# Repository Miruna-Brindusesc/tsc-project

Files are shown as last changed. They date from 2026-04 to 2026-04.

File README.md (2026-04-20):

# Proiect InkTime: Smartwatch nRF52840

## 1\. Diagrama Bloc

Diagrama de mai jos ilustreaza interconexiunile dintre unitatea centrala (MCU) si perifericele sistemului.

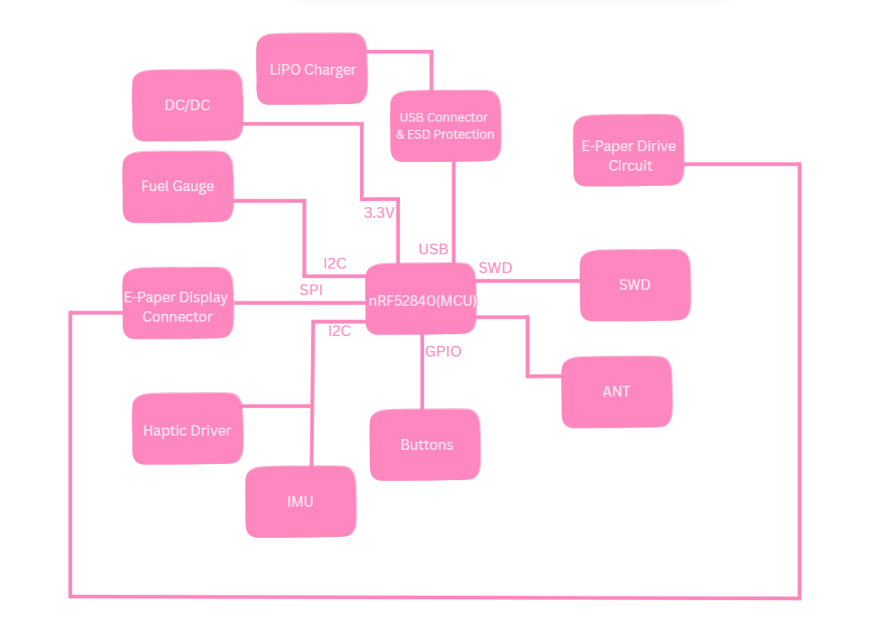
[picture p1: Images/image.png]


## 2\. Descriere Hardware

Ceasul este construit in jurul lui **nRF52840**, ales special pentru ca e foarte eficient si are Bluetooth inclus. Ideea de baza: consumam curent doar cand e absolut necesar.

### 2.1. Creierul (MCU)
* **nRF52840:** Un cip puternic care stie si Bluetooth 5.0 si USB. Are doua cristale de cuart pentru precizie maxima la masurarea timpului.
* **Antena:** Semnalul pleaca spre o antena ceramica. Ca sa avem semnal bun, am decupat planul de cupru de sub ea (zona de "keep-out").

### 2.2. Power & Battery
* **incarcare (BQ25180):** Se ocupa de alimentarea bateriei LiPo prin USB-C. il controlam prin **I2C** ca sa stim cand s-a incarcat.
* **Fuel Gauge (MAX17048):** E senzorul. Ne spune exact cat % mai are bateria, cu o eroare de sub 1%.
* **Regulator (RT6160A):** Transforma tensiunea variabila a bateriei intr-un **3.3V stabil** pentru toate componentele.
* **Protectie ESD:** Langa mufa USB-C am pus un cip minuscul (USBLC6) care atenueaza socurile de electricitate statica sa nu prajim placa.

### 2.3. Ecran si Vibratii
* **E-Paper Display:** Cel mai mare avantaj. Consuma curent **doar cand schimba imaginea**. Daca ceasul sta pe loc, consumul e zero.
* **Driverul de ecran:** Pentru ca ecranul are nevoie de tensiuni mari ca sa miste cerneala electronica, am adaugat un circuit special cu diode si condensatori de 50V.
* **Vibratii (Haptic):** Folosim un driver **DRV2605** care misca motorasul. E mult mai destept decat un simplu tranzistor, oferind vibratii mai fine.

### 2.4. Senzori si Butoane
* **Miscare (BMA423):** Accelerometrul care numara pasii. L-am legat pe **I2C** si are pini de intrerupere (INT) ca sa „trezeasca” ceasul cand ridici mana.
* **Butoane:** Avem 3 butoane cu filtre hardware (rezistente si condensatori) ca sa nu avem probleme cu „apasarile false” (debounce).

## 3\. Asociere pini

| Grupa de pini | Pini folositi | Componenta | Justificarea alegerii / Functia |
| :--- | :--- | :--- | :--- |
| **I2C (SDA/SCL)** | **P0.26 / P0.27** | BQ25180, MAX17048, BMA423, DRV2605 | Magistrala comuna; pinii au fost pozitionati departe de zona antenei pentru a evita interferentele RF. |
| **Display (SPI)** | **P0.13, P0.14, P0.19** | E-Paper Connector | Rutare scurta si directa catre conectorul FPC, minimizand lungimea traseelor de mare viteza. |
| **Display Control** | **P0.20, P0.21, P0.23** | E-Paper Connector | Pini GPIO pentru semnalele de DC, Reset si Busy. Pinul Busy actioneaza ca intrerupere (INT). |
| **Power Gate** | **P0.24** | Tranzistor Q1 (Load Switch) | Ofera curent suficient pentru a comuta poarta MOSFET-ului, oprind complet ecranul in standby. |
| **Butoane & Alerte**| **P1.00 - P1.06** | Butoane externe, Alerte IMU / Baterie | Folosirea exclusiva a Portului 1 pentru semnale lente/intreruperi, izolandu-le de magistralele de date si permitand functia de Wake-Up eficient. |
| **Haptic Enable** | **P0.25** | DRV2605 (Motor Haptic) | Pin GPIO folosit pentru pornirea/oprirea cipului haptic. |
| **USB** | **VBUS, D+, D-** | Conector USB-C | Pini hardware dedicati ai PHY-ului intern nRF52840 pentru comunicatie nativa. |
| **Programare (SWD)** | **SWDIO, SWDCLK, SWO**| Conector Tag-Connect | Pini dedicati din fabrica pentru interfata Serial Wire Debug. |
| **Ceas (Oscilator)** | **P0.00, P0.01** | Cristal 32.768 kHz | Pini hardware dedicati (LFXO) pentru conectarea cristalului extern necesar functiilor de Low-Power Sleep. |

## 4\. BOM
| Qty | Componenta | Designator | Cod JLC / Sursa | Datasheet / Link |
| :--- | :--- | :--- | :--- | :--- |
| 1 | **nRF52840 (MCU)** | U1 | [C190740](https://www.google.com/search?q=https://jlcpcb.com/partdetail/NordicSemicon-NRF52840_QIAA/C190740) | [Datasheet](https://www.google.com/search?q=https://infocenter.nordicsemi.com/pdf/nRF52840_PS_v1.1.pdf) |
| 1 | **BMA423 (IMU)** | IC3 | [C262-BMA423](https://jlcpcb.com/parts) | [Datasheet](https://www.google.com/search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) |
| 1 | **BQ25180 (Charger)** | IC1 | [C595-BQ25180](https://jlcpcb.com/parts) | [Datasheet](https://www.ti.com/lit/ds/symlink/bq25180.pdf) |
| 1 | **MAX17048 (Fuel Gauge)** | U3 | [C329239](https://jlcpcb.com/parts) | [Datasheet](https://www.google.com/search?q=https://datasheets.maximintegrated.com/en/ds/MAX17048-MAX17049.pdf) |
| 1 | **RT6160A (DC/DC)** | IC9 | [C835-RT6160](https://jlcpcb.com/parts) | [Datasheet](https://www.google.com/search?q=https://www.richtek.com/assets/product_pdf/RT6160A/DS6160A-02.pdf) |
| 1 | **DRV2605 (Haptic)** | IC4 | [C519213](https://jlcpcb.com/parts) | [Datasheet](https://www.ti.com/lit/ds/symlink/drv2605.pdf) |
| 1 | **E-Paper Conn (24 pin)**| J1 | [C262444](https://jlcpcb.com/parts) | [Link Molex](https://www.molex.com/en-us/products/part-detail/5034802400) |
| 1 | **USB-C (16 pin)** | J4 | [C719112](https://jlcpcb.com/parts) | [Datasheet](https://www.google.com/search?q=https://datasheet.lcsc.com/lcsc/2110271930_KINGHELM-KH-TYPE-C-16P_C2835407.pdf) |
| 1 | **Antena 2.45GHz** | ANT1 | [C96280](https://jlcpcb.com/parts) | [Datasheet](https://www.johansontechnology.com/datasheets/2450AT18B100.pdf) |
| 3 | **Butoane EVP-AKE31A** | SW1-SW3 | [C519154](https://jlcpcb.com/parts) | [Datasheet](https://www.google.com/search?q=https://industrial.panasonic.com/cdbs/www-data/pdf/SMG0000/SMG0000C191.pdf) |
| 1 | **USBLC6-2 (ESD)** | D3 | [C75248](https://jlcpcb.com/parts) | [Datasheet](https://www.st.com/resource/en/datasheet/usblc6-2.pdf) |
| 1 | **DMG2305UX (P-FET)** | Q1 | [C14388](https://jlcpcb.com/parts) | [Datasheet](https://www.diodes.com/assets/Datasheets/DMG2305UX.pdf) |

## 5\. Decizii

### 5.1. Decizii de amplasare a componentelor

Privind asezarea componentelor pe PCB, au fost luate urmatoarele decizii strategice pentru a optimiza spatiul si performanta:

* **Planuri de Masa (GND Pours) pe ambele straturi:** Am implementat poligoane de GND atat pe stratul Top, cat si pe Bottom, cusute cu via-uri (vias). Aceasta decizie are trei roluri majore:
    1.  **Ecranare EMI:** Reduce zgomotul electric dintre traseele de semnal.
    2.  **Disipare Termica:** Ajuta la disiparea caldurii generate de convertorul DC/DC si de circuitul de incarcare a bateriei.
    3.  **Referinta RF:** Ofera un plan de referinta solid pentru performanta optima a antenei Bluetooth.
* **Amplasarea Antenei (RF Keep-out Zone):** Antena ceramica de 2.4GHz a fost plasata pe extrema dreapta a placii.

* **Gruparea Circuitului E-Paper:** Componentele voluminoase si zgomotoase aferente display-ului (bobina, diodele si condensatorii pentru tensiunile de VGH/VGL) sunt grupate extrem de compact in stanga, imediat langa conectorul FPC. Aceasta mentine traseele de inalta tensiune scurte si departe de liniile sensibile ale MCU-ului.

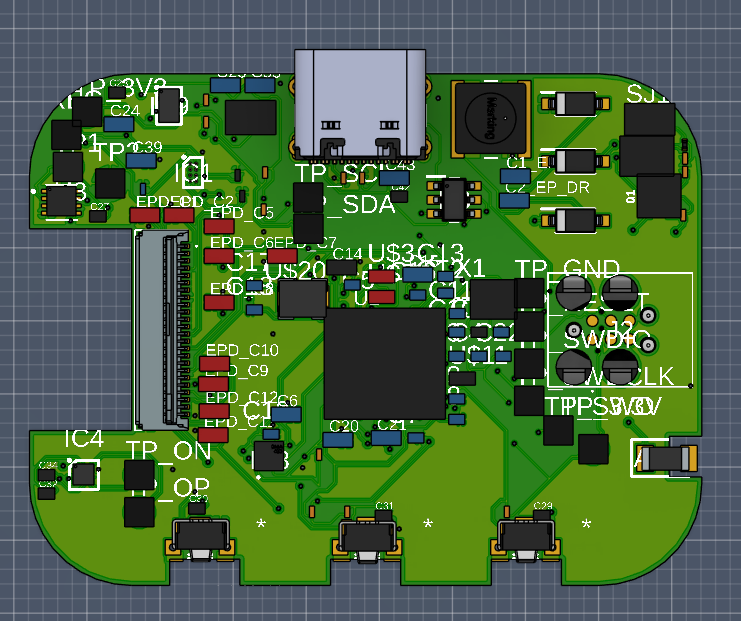
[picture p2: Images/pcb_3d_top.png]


### 5.2. Erori

#### Erori ERC (Electrical Rule Check)
* **Conflicte de alimentare (U1, U3):** Softul da eroare pentru ca mai multi pini `VDD` se leaga la aceeasi retea (`3V3` sau `VBAT`). Conexiunile sunt 100% corecte conform datasheet-urilor; eroarea apare doar pentru ca softul e prea strict cu regulile de „Power Source”.
* **Pinii de decuplare (DEC1, DEC4):** Aceeasi poveste la nRF52840. Pinii sunt legati corect la condensatori externi exact cum cere producatorul, dar softul nu ii recunoaste ca noduri clasice de alimentare.
* **Componente fara valoare (SJ1):** Jumper-ul de pe placa (SJ1) este doar un bridge fizic (Solder Jumper) folosit pentru configurare. Fiind un simplu contact de fludor, e normal sa nu aiba o valoare numerica (gen 10kΩ).
* **Erorile de tip "Only one pin on net"** (pe SDA/SCL) arata ca acele trasee sunt lasate libere.

#### Erori DRC (Design Rule Check)
Deoarece acest PCB este un *Proof of Concept* software si nu merge fizic la o fabrica, am prioritizat logica si functionalitatea in fata unui raport DRC complet verde:
* **Erori de margine (Board Outline Clearance):** Sunt 8 erori aici.Conectorul USB-C si butoanele sunt apropiate de marginile placutei, ceea ce declanseaza automat eroarea.
* **Suprapuneri pe planul de masa (Polygon Overlap):** Placa foloseste piese minuscule (0201/0402) si este foarte aglomerata. Am fortat poligonul de masa (GND) sa acopere cat mai mult spatiu pentru o buna disipare termica. Asta a generat niste erori de "clearance" la pad-uri, dar am preferat un plan de masa solid in detrimentul unui DRC perfect.

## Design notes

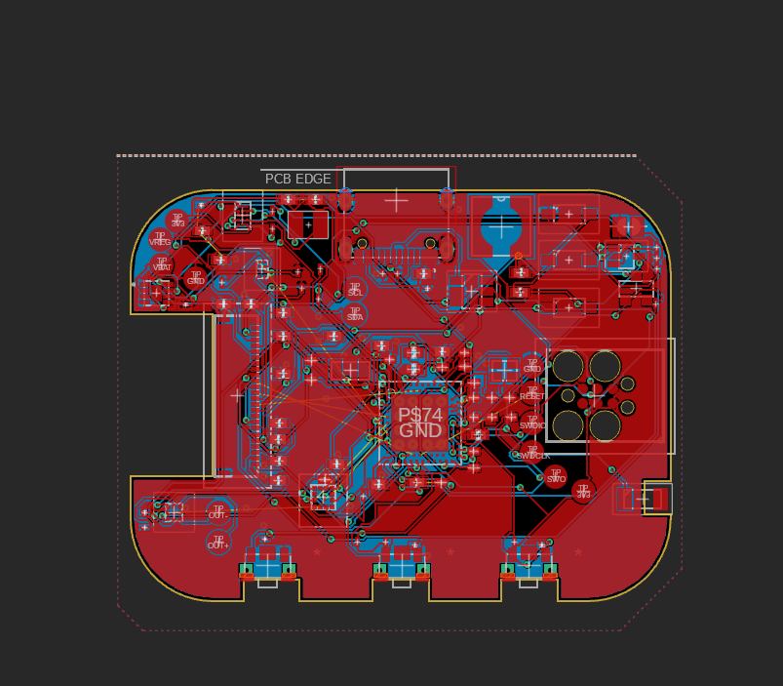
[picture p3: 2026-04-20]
Images/pcb_2d.png

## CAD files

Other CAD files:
Mechanical/PCB_3d.f3d
Mechanical/exploded_view.f3z

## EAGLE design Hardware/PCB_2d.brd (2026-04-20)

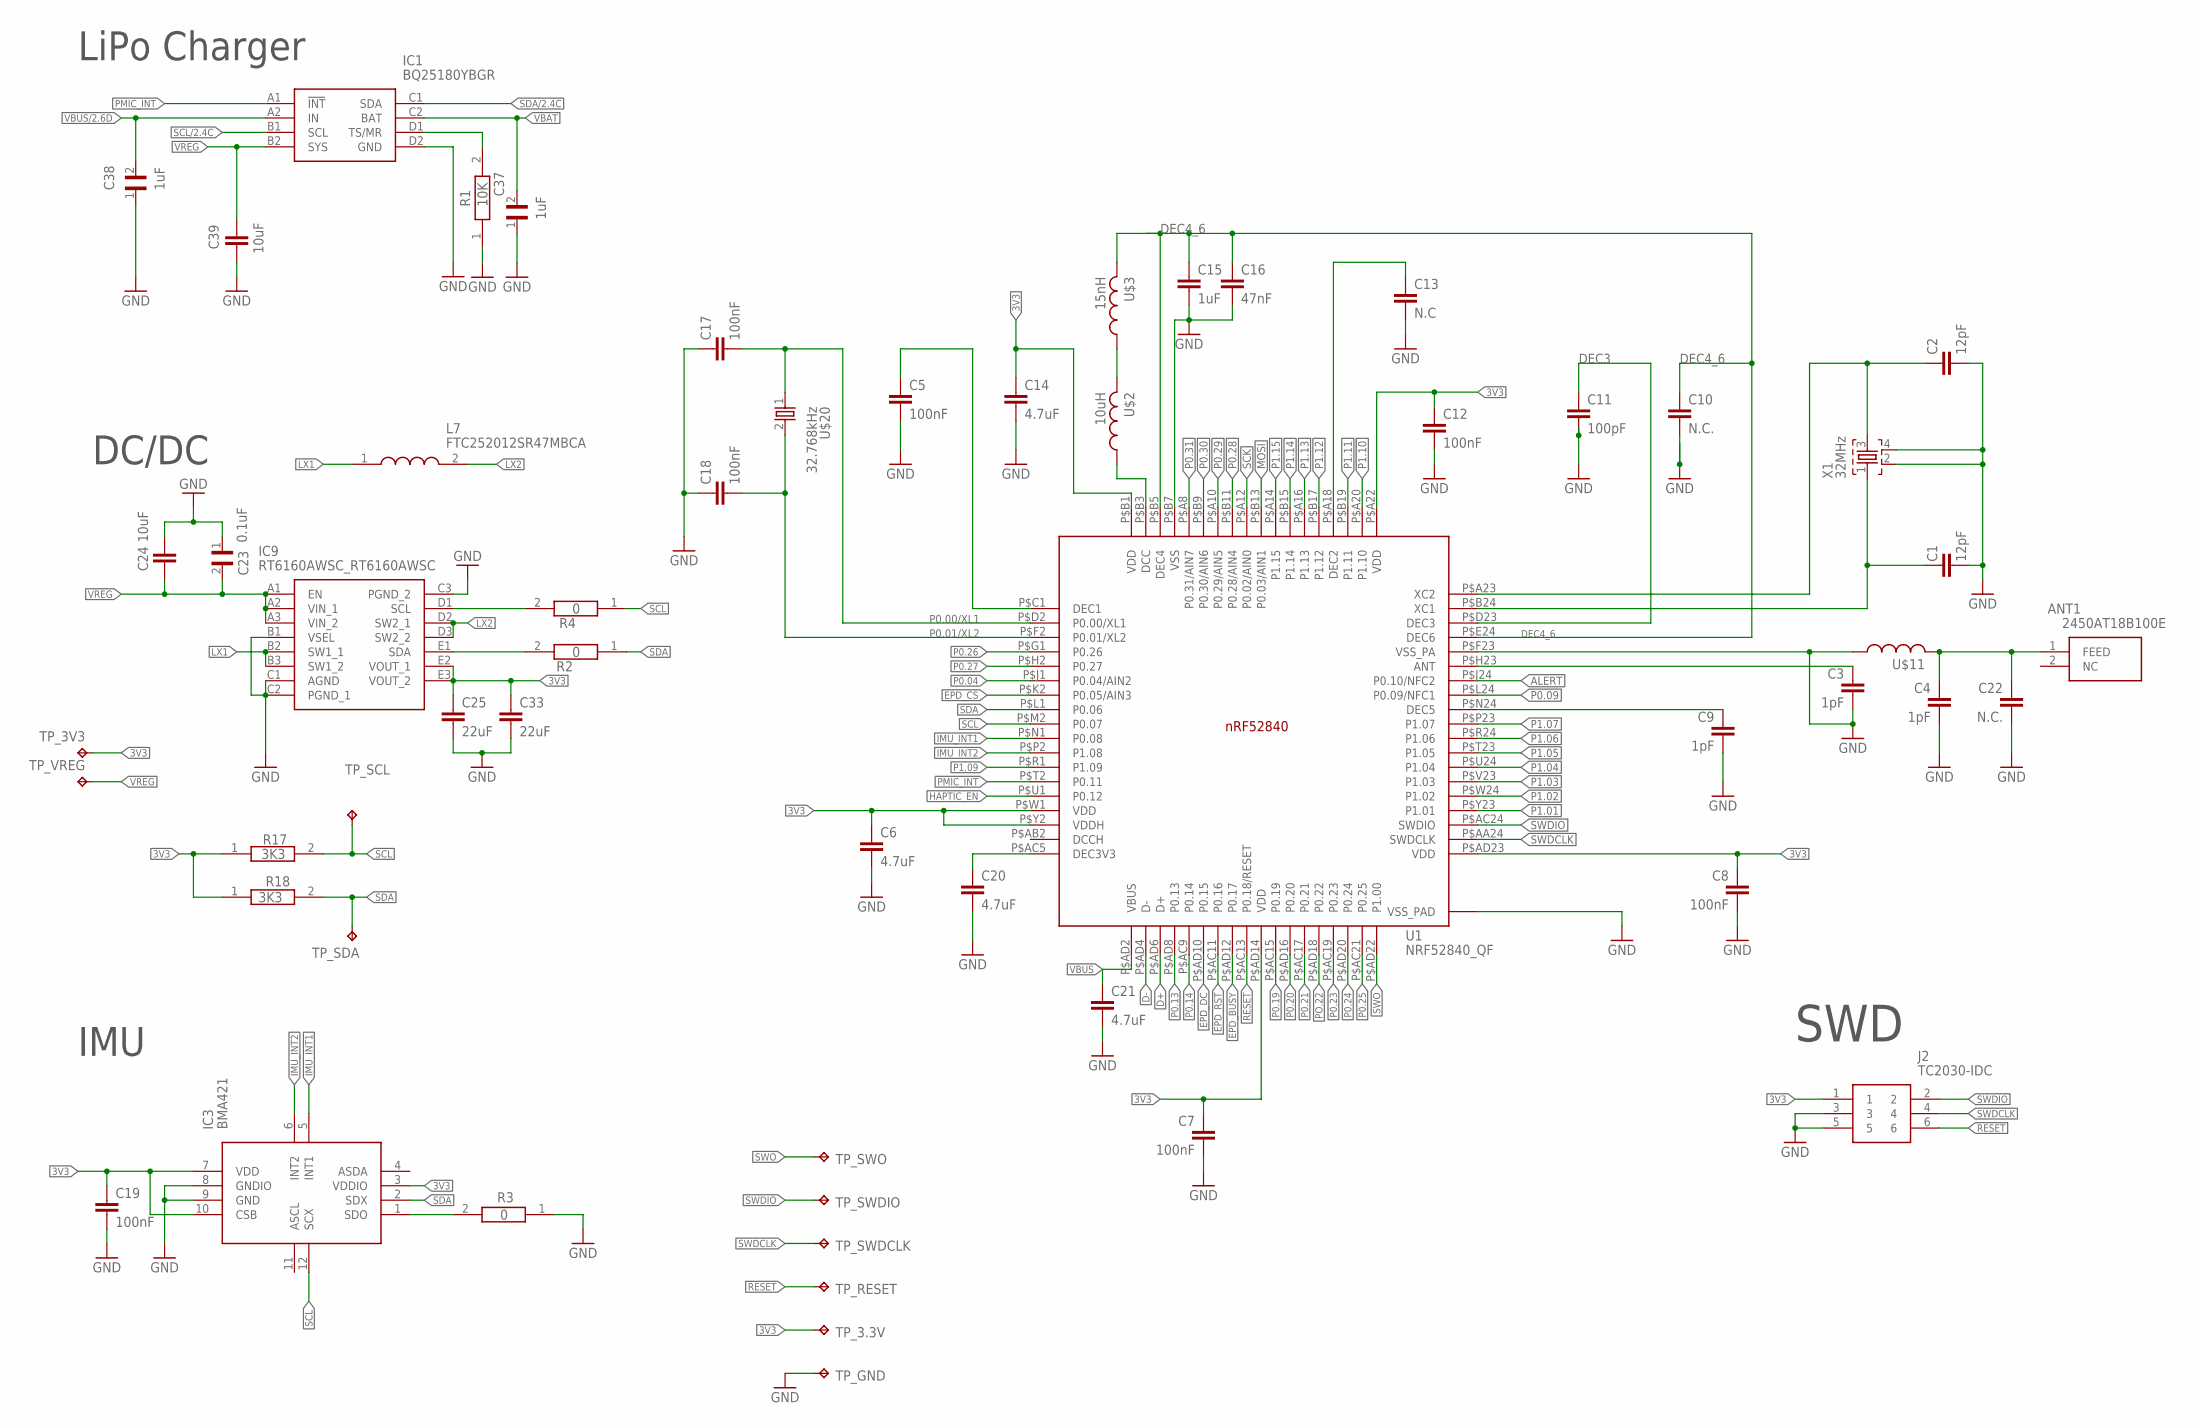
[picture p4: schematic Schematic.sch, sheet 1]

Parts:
ANT1: 2450AT18B100E; 2450AT18B100E_ANTC3216X140N
C1, C2: 12pF; NORDIC_NRF_3_RESC0201_L
C3, C4, C9: 1pF; NORDIC_NRF_3_RESC0201_L
C5, C7, C8, C12, C17, C18, C19: 100nF; NORDIC_NRF_3_RESC0201_L
C6, C14, C20, C21: 4.7uF; PERFECT_0402_0402
C10, C22: N.C.; NORDIC_NRF_3_RESC0201_L
C11: 100pF; NORDIC_NRF_3_RESC0201_L
C13: N.C; NORDIC_NRF_3_RESC0201_L
C15: 1uF; PERFECT_0402_0402
C16: 47nF; NORDIC_NRF_3_RESC0201_L
C23: 0.1uF; GRM011R60J152KE01L_2_CAPC0201X13N
C24, C39: 10uF; PERFECT_0402_0402
C25, C33: 22uF; PERFECT_0402_0402
C37, C38: 1uF; GRM011R60J152KE01L_1_0201
IC1: BQ25180YBGR; BQ25180YBGR_BGA8C40P2X4_100X155X50
IC3: BMA421; BMA423_BMA423
IC9: RT6160AWSC_RT6160AWSC; RT6160AWSC_BGA15C40P3X5_140X230X60
J2: TC2030-IDC; TC2030-IDC_TC2030IDC
L7: FTC252012SR47MBCA; MLP2016SR47MT0S1_INDC2016X100N
R1: 10K; CPF0201D7K68C1_0201
R2, R3, R4: 0; CPF0201D7K68C1_0201
R17, R18: 3K3; CPF0201D7K68C1_0201
TP_3.3V, TP_3V3: HECTOR_WATCH_1_TPTP20R; HECTOR_WATCH_1_TP20R
TP_GND: HECTOR_WATCH_1_TPTP20R; HECTOR_WATCH_1_TP20R
TP_RESET: HECTOR_WATCH_1_TPTP20R; HECTOR_WATCH_1_TP20R
TP_SCL: HECTOR_WATCH_1_TPTP20R; HECTOR_WATCH_1_TP20R
TP_SDA: HECTOR_WATCH_1_TPTP20R; HECTOR_WATCH_1_TP20R
TP_SWDCLK: HECTOR_WATCH_1_TPTP20R; HECTOR_WATCH_1_TP20R
TP_SWDIO: HECTOR_WATCH_1_TPTP20R; HECTOR_WATCH_1_TP20R
TP_SWO: HECTOR_WATCH_1_TPTP20R; HECTOR_WATCH_1_TP20R
TP_VREG: HECTOR_WATCH_1_TPTP20R; HECTOR_WATCH_1_TP20R
U1: NRF52840_QF; NORDIC_NRF_4_AQFN50P700X700X85_HS-74N
U$2: 10uH; NORDIC_NRF_2_RESC0402_L
U$3: 15nH; NORDIC_NRF_2_RESC0402_L
U$11: NORDIC_NRF_2_INDUCTOR_0402_L; NORDIC_NRF_2_RESC0402_L
U$20: 32.768kHz; NORDIC_NRF_1_XTAL_3215_N
X1: 32MHz; NORDIC_NRF_BT-XTAL_2016_N

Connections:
3V3: C6.1, C7.1, C8.1, C12.1, C14.1, C19.1, C25.1, C33.1, IC3.3 (VDDIO), IC3.7 (VDD), IC3.10 (CSB), IC9.E2 (VOUT_1), IC9.E3 (VOUT_2), J2.1, R17.1, R18.1, TP_3.3V.TP, TP_3V3.TP, U1.P$A22 (VDD), U1.P$AD14 (VDD), U1.P$AD23 (VDD), U1.P$B1 (VDD), U1.P$W1 (VDD), U1.P$Y2 (VDDH); also elsewhere on the board
ALERT: U1.P$J24 (P0.10/NFC2); also elsewhere on the board
D+: U1.P$AD6 (D+); also elsewhere on the board
D-: U1.P$AD4 (D-); also elsewhere on the board
DEC3: C11.1, U1.P$D23 (DEC3)
DEC4_6: C10.1, C15.1, C16.1, U1.P$B5 (DEC4), U1.P$E24 (DEC6), U$3.2
EPD_BUSY: U1.P$AD12 (P0.17); also elsewhere on the board
EPD_CS: U1.P$K2 (P0.05/AIN3); also elsewhere on the board
EPD_DC: U1.P$AD10 (P0.15); also elsewhere on the board
EPD_RST: U1.P$AC11 (P0.16); also elsewhere on the board
GND: C1.2, C2.2, C3.2, C4.2, C5.2, C6.2, C7.2, C8.2, C9.2, C10.2, C11.2, C12.2, C13.2, C14.2, C15.2, C16.2, C17.1, C18.1, C19.2, C20.2, C21.2, C22.2, C23.1, C24.1, C25.2, C33.2, C37.1, C38.1, C39.2, IC1.D2 (GND), IC3.8 (GNDIO), IC3.9 (GND), IC9.B1 (VSEL), IC9.C1 (AGND), IC9.C2 (PGND_1), IC9.C3 (PGND_2), J2.3, J2.5, R1.1, R3.1, TP_GND.TP, U1.P$74 (VSS_PAD), U1.P$75 (VSS_PAD), U1.P$76 (VSS_PAD), U1.P$77 (VSS_PAD), U1.P$78 (VSS_PAD), U1.P$79 (VSS_PAD), U1.P$80 (VSS_PAD), U1.P$81 (VSS_PAD), U1.P$82 (VSS_PAD), U1.P$83 (VSS_PAD), U1.P$84 (VSS_PAD), U1.P$85 (VSS_PAD), U1.P$86 (VSS_PAD), U1.P$87 (VSS_PAD), U1.P$88 (VSS_PAD), U1.P$89 (VSS_PAD), U1.P$90 (VSS_PAD), U1.P$B7 (VSS), U1.P$F23 (VSS_PA), U$11.1, X1.2, X1.4; also elsewhere on the board
HAPTIC_EN: U1.P$U1 (P0.12); also elsewhere on the board
IMU_INT1: IC3.5 (INT1), U1.P$N1 (P0.08)
IMU_INT2: IC3.6 (INT2), U1.P$P2 (P1.08)
LX1: IC9.B2 (SW1_1), IC9.B3 (SW1_2), L7.1
LX2: IC9.D2 (SW2_1), IC9.D3 (SW2_2), L7.2
MOSI: U1.P$B13 (P0.03/AIN1); also elsewhere on the board
unnamed: U1.P$B3 (DCC), U$2.1
unnamed: U$2.2, U$3.1
unnamed: C13.1, U1.P$A18 (DEC2)
unnamed: IC9.E1 (SDA), R2.2
unnamed: IC9.D1 (SCL), R4.2
unnamed: C1.1, U1.P$B24 (XC1), X1.1
unnamed: C2.1, U1.P$A23 (XC2), X1.3
unnamed: ANT1.1 (FEED), C4.1, C22.1, U$11.2
unnamed: C3.1, U1.P$H23 (ANT)
unnamed: C9.1, U1.P$N24 (DEC5)
unnamed: C5.1, U1.P$C1 (DEC1)
unnamed: C20.1, U1.P$AC5 (DEC3V3)
unnamed: IC1.D1 (TS/MR), R1.2
unnamed: IC3.1 (SDO), R3.2
P0.00/XL1: C17.2, U1.P$D2 (P0.00/XL1), U$20.1
P0.01/XL2: C18.2, U1.P$F2 (P0.01/XL2), U$20.2
P0.04: U1.P$J1 (P0.04/AIN2)
P0.09: U1.P$L24 (P0.09/NFC1)
P0.13: U1.P$AD8 (P0.13); also elsewhere on the board
P0.14: U1.P$AC9 (P0.14); also elsewhere on the board
P0.19: U1.P$AC15 (P0.19)
P0.20: U1.P$AD16 (P0.20)
P0.21: U1.P$AC17 (P0.21)
P0.23: U1.P$AC19 (P0.23)
P0.24: U1.P$AD20 (P0.24)
P0.25: U1.P$AC21 (P0.25)
P0.26: U1.P$G1 (P0.26)
P0.27: U1.P$H2 (P0.27)
P0.28: U1.P$B11 (P0.28/AIN4)
P0.29: U1.P$A10 (P0.29/AIN5)
P0.30: U1.P$B9 (P0.30/AIN6)
P0.31: U1.P$A8 (P0.31/AIN7)
P1.01: U1.P$Y23 (P1.01); also elsewhere on the board
P1.02: U1.P$W24 (P1.02); also elsewhere on the board
P1.03: U1.P$V23 (P1.03)
P1.04: U1.P$U24 (P1.04)
P1.05: U1.P$T23 (P1.05)
P1.06: U1.P$R24 (P1.06)
P1.07: U1.P$P23 (P1.07)
P1.09: U1.P$R1 (P1.09)
P1.10: U1.P$A20 (P1.10)
P1.11: U1.P$B19 (P1.11)
P1.12: U1.P$B17 (P1.12)
P1.13: U1.P$A16 (P1.13)
P1.14: U1.P$B15 (P1.14)
P1.15: U1.P$A14 (P1.15)
PMIC_INT: IC1.A1 (!INT), U1.P$T2 (P0.11)
PO.22: U1.P$AD18 (P0.22)
RESET: J2.6, TP_RESET.TP, U1.P$AC13 (P0.18/RESET)
SCK: U1.P$A12 (P0.02/AIN0); also elsewhere on the board
SCL: IC3.12 (SCX), R4.1, R17.2, TP_SCL.TP, U1.P$M2 (P0.07); also elsewhere on the board
SCL/2.4C: IC1.B1 (SCL)
SDA: IC3.2 (SDX), R2.1, R18.2, TP_SDA.TP, U1.P$L1 (P0.06); also elsewhere on the board
SDA/2.4C: IC1.C1 (SDA)
SWDCLK: J2.4, TP_SWDCLK.TP, U1.P$AA24 (SWDCLK)
SWDIO: J2.2, TP_SWDIO.TP, U1.P$AC24 (SWDIO)
SWO: TP_SWO.TP, U1.P$AD22 (P1.00)
VBAT: C37.2, IC1.C2 (BAT); also elsewhere on the board
VBUS: C21.1, U1.P$AD2 (VBUS); also elsewhere on the board
VBUS/2.6D: C38.2, IC1.A2 (IN)
VREG: C23.2, C24.2, C39.1, IC1.B2 (SYS), IC9.A1 (EN), IC9.A2 (VIN_1), IC9.A3 (VIN_2), TP_VREG.TP

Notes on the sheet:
DC/DC
LiPo Charger
IMU
SWD

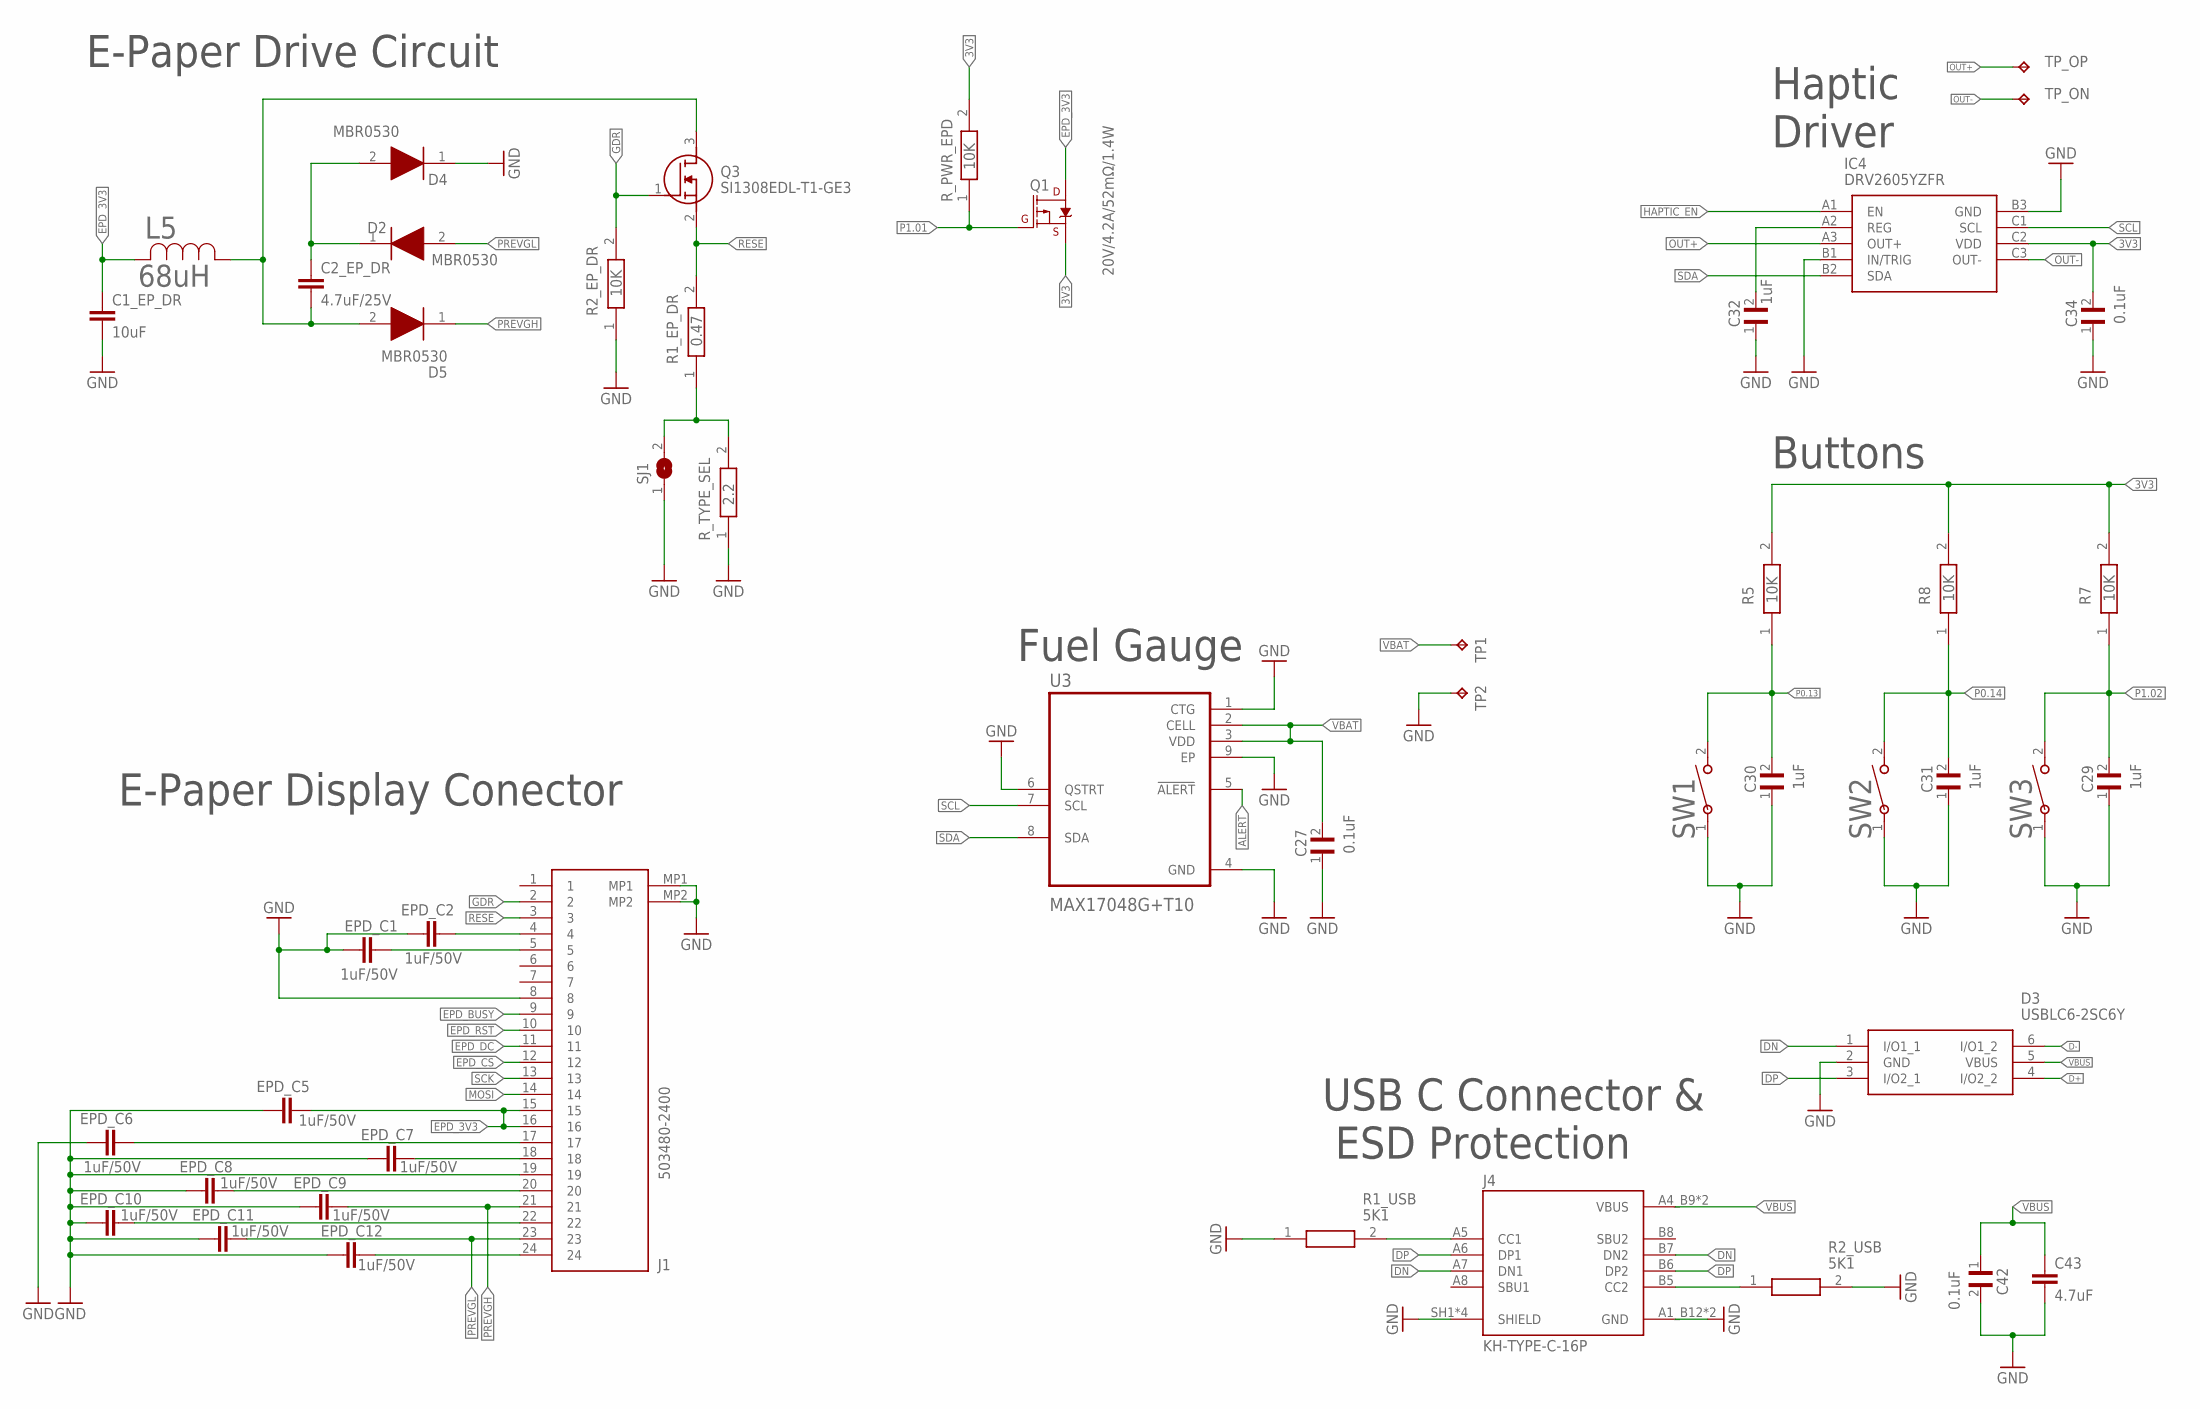
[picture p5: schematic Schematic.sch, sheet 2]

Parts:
C1_EP_DR: 10uF; PERFECT_0402_0402
C2_EP_DR: 4.7uF/25V; PERFECT_0402_0402
C27, C34, C42: 0.1uF; GRM011R60J152KE01L_2_CAPC0201X13N
C29, C30, C31, C32: 1uF; GRM011R60J152KE01L_2_CAPC0201X13N
C43: 4.7uF; PERFECT_0402_0402
D2, D4, D5: MBR0530; ESP32_C6_LIBRARY_5_SOD3716X135N
D3: USBLC6-2SC6Y; ESP32_C6_LIBRARY_3_SOT95P280X145-6N
EPD_C1, EPD_C2, EPD_C5, EPD_C6, EPD_C7, EPD_C8, EPD_C9, EPD_C10, EPD_C11, EPD_C12: 1uF/50V; PERFECT_0402_0402
IC4: DRV2605YZFR; DRV2605YZFR_BGA9C50P3X3_144X144X62
J1: 503480-2400; 503480-2400_5034802400
J4: KH-TYPE-C-16P; KH-TYPE-C-16P_KINGHELM_KH-TYPE-C-16P
L5: 68uH; ESP32_C6_LIBRARY_2_IND_4828-WE-TPC_WRE
Q1: 20V/4.2A/52mΩ/1.4W; ESP32_C6_LIBRARY_4_ESP32_C6_LIBRARY_4_ESP32_C6_LIBRARY_4_ES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
Q3: SI1308EDL-T1-GE3; ESP32_C6_LIBRARY_6_SOT65P210X110-3N
R1_EP_DR: 0.47; CPF0201D7K68C1_0201
R1_USB, R2_USB: 5K1; CPF0201D7K68C1_0201
R2_EP_DR, R5, R7, R8: 10K; CPF0201D7K68C1_0201
R_PWR_EPD: 10K; CPF0201D7K68C1_0201
R_TYPE_SEL: 2.2; CPF0201D7K68C1_0201
SJ1: ESP32_C6_LIBRARY_7_JUMPER_SJ
SW1, SW2, SW3: 2025-10-22_07-23-44_LIBRARY_EVP-AKE31ASW_EVP-AKE3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; 2025-10-22_07-23-44_LIBRARY_SW_EVP-AKE31A_PAN
TP1, TP2: HECTOR_WATCH_1_TPTP20R; HECTOR_WATCH_1_TP20R
TP_ON: HECTOR_WATCH_1_TPTP20R; HECTOR_WATCH_1_TP20R
TP_OP: HECTOR_WATCH_1_TPTP20R; HECTOR_WATCH_1_TP20R
U3: MAX17048G+T10; ESP32_C6_LIBRARY_SON50P200X200X80-9N

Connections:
3V3: C34.2, IC4.C2 (VDD), Q1.2 (S), R5.2, R7.2, R8.2, R_PWR_EPD.2; also elsewhere on the board
ALERT: U3.5 (!ALERT); also elsewhere on the board
D+: D3.4 (I/O2_2); also elsewhere on the board
D-: D3.6 (I/O1_2); also elsewhere on the board
DN: D3.1 (I/O1_1), J4.A7 (DN1), J4.B7 (DN2)
DP: D3.3 (I/O2_1), J4.A6 (DP1), J4.B6 (DP2)
EPD_3V3: C1_EP_DR.1, EPD_C5.2, J1.15, J1.16, L5.2, Q1.3 (D)
EPD_BUSY: J1.9; also elsewhere on the board
EPD_CS: J1.12; also elsewhere on the board
EPD_DC: J1.11; also elsewhere on the board
EPD_RST: J1.10; also elsewhere on the board
GDR: J1.2, Q3.1 (G), R2_EP_DR.2
GND: C1_EP_DR.2, C27.1, C29.1, C30.1, C31.1, C32.1, C34.1, C42.2, C43.2, D3.2 (GND), D4.1 (K), EPD_C1.1, EPD_C2.1, EPD_C5.1, EPD_C6.1, EPD_C7.1, EPD_C8.1, EPD_C9.1, EPD_C10.1, EPD_C11.1, EPD_C12.1, IC4.B1 (IN/TRIG), IC4.B3 (GND), J1.8, J1.19, J1.MP1, J1.MP2, J4.A1_B12 (GND), J4.A12_B1 (GND), J4.SH1 (SHIELD), J4.SH2 (SHIELD), J4.SH3 (SHIELD), J4.SH4 (SHIELD), R1_USB.1, R2_EP_DR.1, R2_USB.2, R_TYPE_SEL.1, SJ1.1, SW1.1, SW2.1, SW3.1, TP2.TP, U3.1 (CTG), U3.4 (GND), U3.6 (QSTRT), U3.9 (EP); also elsewhere on the board
HAPTIC_EN: IC4.A1 (EN); also elsewhere on the board
MOSI: J1.14; also elsewhere on the board
unnamed: EPD_C2.2, J1.4
unnamed: C2_EP_DR.1, D2.1 (K), D4.2 (A)
unnamed: C2_EP_DR.2, D5.2 (A), L5.1, Q3.3 (D)
unnamed: R1_EP_DR.1, R_TYPE_SEL.2, SJ1.2
unnamed: EPD_C1.2, J1.5
unnamed: EPD_C6.2, J1.17
unnamed: EPD_C7.2, J1.18
unnamed: EPD_C8.2, J1.20
unnamed: J4.A5 (CC1), R1_USB.2
unnamed: EPD_C10.2, J1.22
unnamed: EPD_C12.2, J1.24
unnamed: J4.B5 (CC2), R2_USB.1
unnamed: C32.2, IC4.A2 (REG)
OUT+: IC4.A3 (OUT+), TP_OP.TP
OUT-: IC4.C3 (OUT-), TP_ON.TP
P0.13: C30.2, R5.1, SW1.2; also elsewhere on the board
P0.14: C31.2, R8.1, SW2.2; also elsewhere on the board
P1.01: Q1.1 (G), R_PWR_EPD.1; also elsewhere on the board
P1.02: C29.2, R7.1, SW3.2; also elsewhere on the board
PREVGH: D5.1 (K), EPD_C9.2, J1.21
PREVGL: D2.2 (A), EPD_C11.2, J1.23
RESE: J1.3, Q3.2 (S), R1_EP_DR.2
SCK: J1.13; also elsewhere on the board
SCL: IC4.C1 (SCL), U3.7 (SCL); also elsewhere on the board
SDA: IC4.B2 (SDA), U3.8 (SDA); also elsewhere on the board
VBAT: C27.2, TP1.TP, U3.2 (CELL), U3.3 (VDD); also elsewhere on the board
VBUS: C42.1, C43.1, D3.5 (VBUS), J4.A4_B9 (VBUS), J4.A9_B4 (VBUS); also elsewhere on the board

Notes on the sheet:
USB C Connector & ESD Protection
Buttons
Fuel Gauge
Haptic Driver
E-Paper Drive Circuit
E-Paper Display Conector

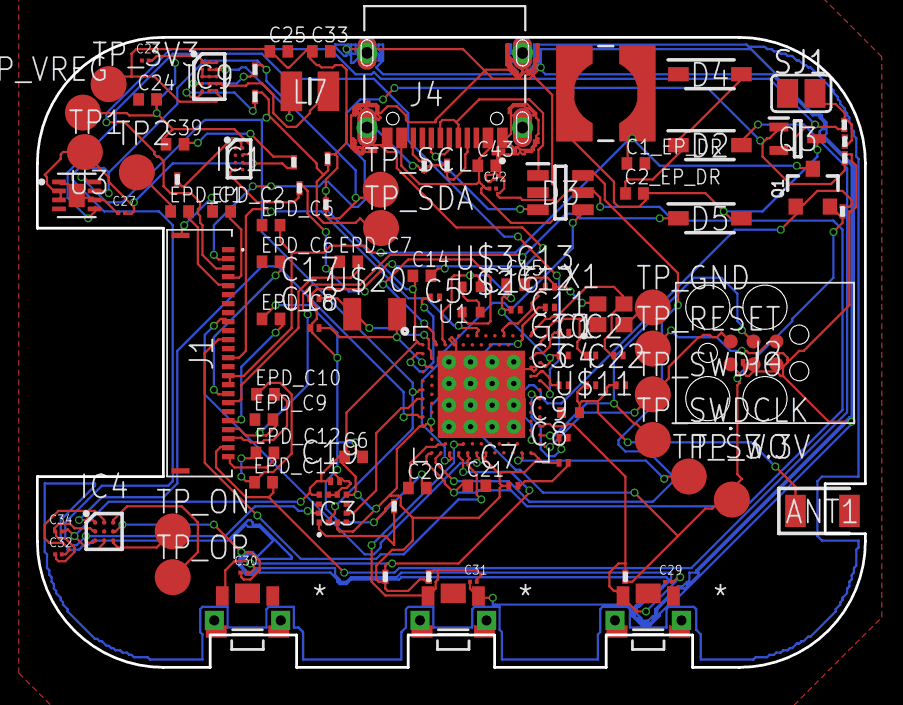
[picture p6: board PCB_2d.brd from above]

Board: 2 copper layers, 46.0 x 35.0 mm, 105 parts (0 on the bottom side), 71 nets.

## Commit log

2026-04-10 Add Manufacturing files and Hardware files
    [PCB_2d.brd, Schematic.sch]
2026-04-20 Add modified files: Schematic, PCB_2d, PCB_3d in .f3d format(Fusion crashes at .step export), exploded_view in .f3z format(same problem), bill.bom, gerbers.zip, pick.cpl.
    [PCB_2d.brd, PCB_3d.f3d, Schematic.sch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]

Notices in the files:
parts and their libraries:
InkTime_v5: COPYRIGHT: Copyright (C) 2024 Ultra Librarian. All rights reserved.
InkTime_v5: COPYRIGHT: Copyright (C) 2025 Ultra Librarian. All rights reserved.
